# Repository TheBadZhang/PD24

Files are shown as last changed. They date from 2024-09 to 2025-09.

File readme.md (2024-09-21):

# PD24
> PD输入24V（可调输出）升压输出模块

## 原理图
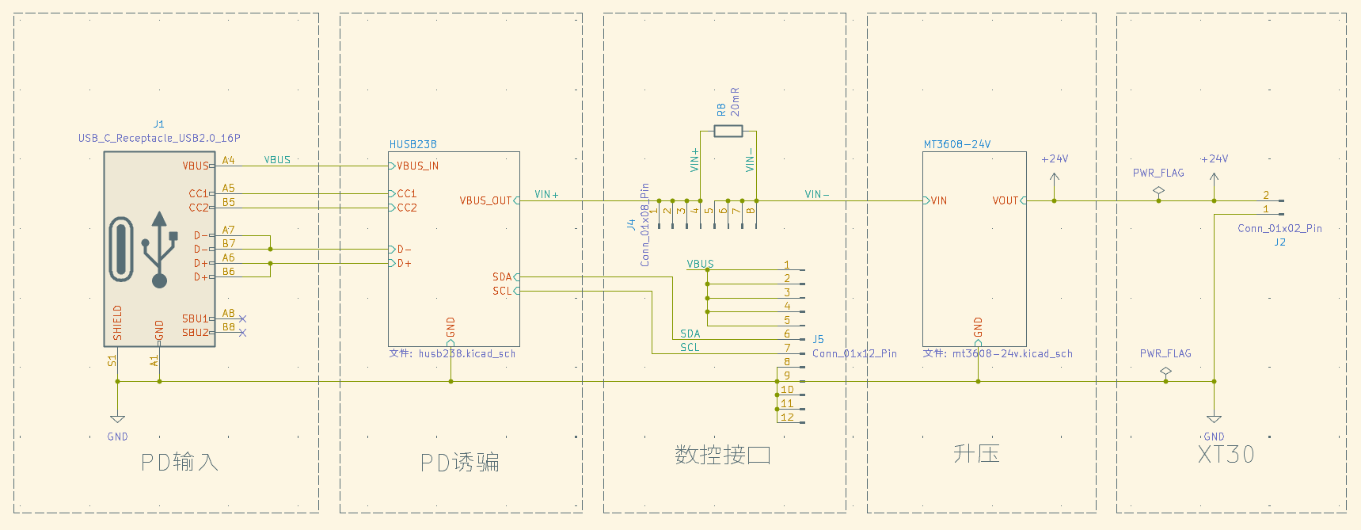
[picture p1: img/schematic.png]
原理图


简单来说就是使用`HUSB238`诱骗PD输出20V（诱骗不到20V就以此往下诱骗，最低5V）的电压，`CSD25402Q3A`过流控制，然后通过`MT3608`升压到24V输出

哪怕完全不支持PD，也可以输出24V，不过能够提供的功率就比较有限了

保留了数控接口，可以将`PD24`的输入电压和总线上的电流电压传给`PD24_ctrl`模块，计划通过INA226读取，并在OLED上显示

## 2D/3D Preview
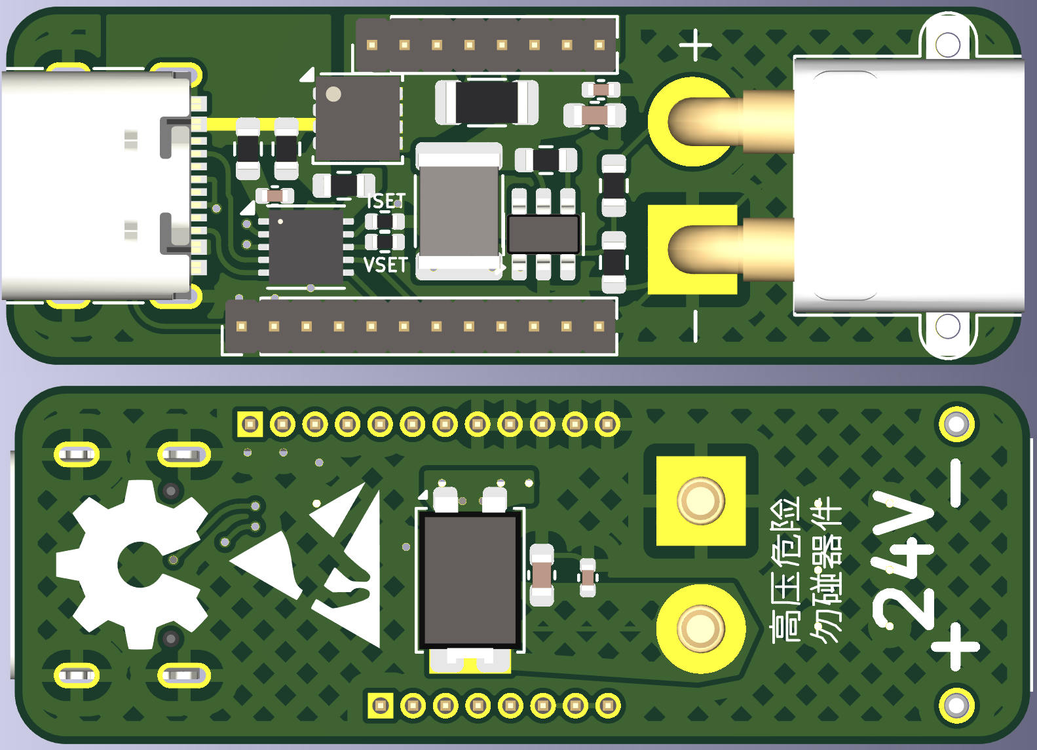
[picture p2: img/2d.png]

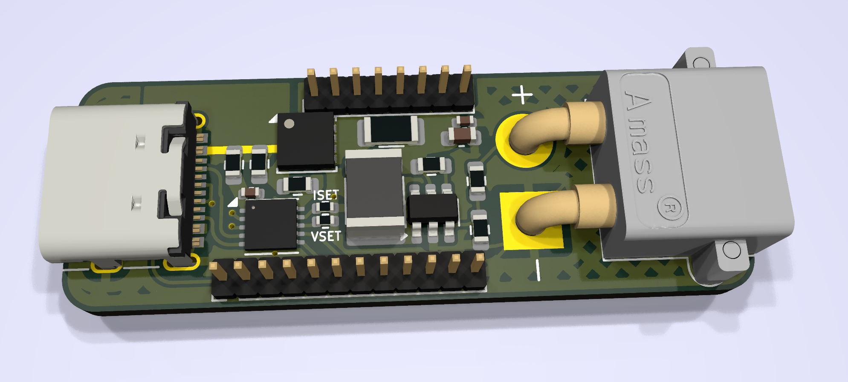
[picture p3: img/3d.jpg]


## 实物焊接
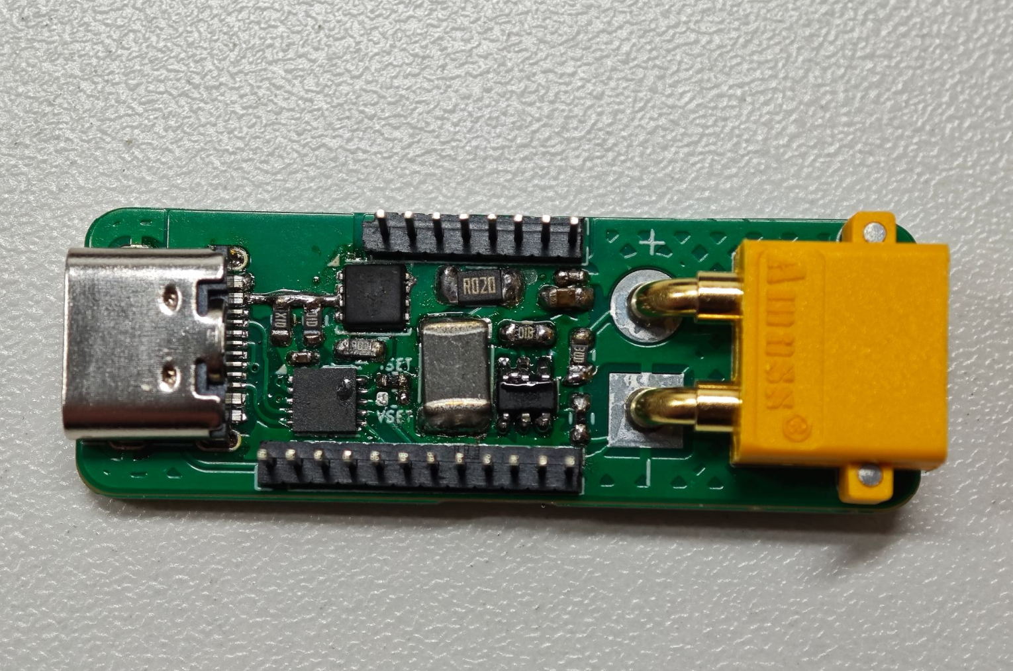
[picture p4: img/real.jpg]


> 因为没有开钢网，所以这些都是用烙铁上锡后用加热台焊接的，经常容易把控不住锡量，焊接比较难看，但是不影响功能

## 后话

这个模块一开始的时候因为电感没有到，所以我就直接焊上去用，结果`MT3608`和电感一下子就烧了，现在想想可能是因为没有焊接输出电容的原因，导致芯片震荡，最终烧掉

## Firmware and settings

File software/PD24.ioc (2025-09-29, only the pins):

Mcu.UserName=STM32G031G8Ux
PA13.Signal=SYS_SWDIO
PA14-BOOT0.Signal=SYS_SWCLK
PA2.GPIO_Label=INT1
PA2.Signal=GPXTI2
PA4.GPIO_Label=CS
PA4.Signal=GPIO_Output
PA5.Signal=SPI1_SCK
PA6.Signal=SPI1_MISO
PA7.Signal=SPI1_MOSI
PA8.GPIO_Label=INA226_ALERT
PA8.Signal=GPIO_Output
PB0.GPIO_Label=KEY1
PB0.Signal=GPIO_Input
PB1.GPIO_Label=KEY2
PB1.Signal=GPIO_Input
PB3.GPIO_Label=KEY3
PB3.Signal=GPIO_Input
PB7.Signal=I2C1_SDA
PB8.Signal=I2C1_SCL

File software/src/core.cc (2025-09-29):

#include "common.h"
#include "core.h"

#include "trick.h"
#include "main.h"

#include <stdio.h>
char strbuf[128] = {0};
uint8_t str_len = 0;

#include <stdint.h>
#include <stdio.h>
#include <string.h>

#include "font.h"
#include "ssd1312.h"

#include "ina226.h"

#include "ws2812.h"

#include "husb238.h"

#include "lis2dw12.h"


char uart_rx_buf[32];


//***********按键处理*************//
enum KEY_EVENT {
	KEY_NONE = 0,
	KEY_DOWN = 1,
	KEY_UP = 2
};

uint16_t key[4] = {0x00};
bool key_flag[4] = {true, true, true, true};

// 一般来说按键扫描函数需要按照5kHz的频率对按键进行扫描
void key_scan(void) {

	key[1] = (key[1] << 1) | ((!read(KEY1))?0x01:0x00);
	key[2] = (key[2] << 1) | ((!read(KEY2))?0x01:0x00);
	key[3] = (key[3] << 1) | ((!read(KEY3))?0x01:0x00);
}
/**
 * @brief 按键处理函数
 * @param i 按键编号
 * @return 0 无按键动作 1 按键按下 2 按键释放
 *
 * @note 该函数会自动处理按键的抖动
 * @note 改函数还需要和按键扫描函数配合使用
 */
uint8_t key_push(uint8_t i) {
	if (key[i] == 0xffff && key_flag[i]) {
		key_flag[i] = false;
		return 1;
	} else if (key[i] == 0x0000 && !key_flag[i]) {
		key_flag[i] = true;
		return 2;
	}

	return 0;
}
bool key_pressed(uint8_t i) {
	return key[i] == 0xffff;
}
bool key_released(uint8_t i) {
	return key[i] == 0x0000;
}


//***********INA226数据处理*************//
float bus_voltage;
int16_t current_raw;
float current;
uint16_t power_raw;
float power;
float power_sum = 0;


void ina226_sample(void) {
	bus_voltage = ina226_getBusV();
	current = ina226_getCurrent();
	power_raw = ina226_getPowerReg();
	power = ina226_getPower();

	// 将电压、电流、功率数据传给上位机
	// int bus_voltage_i = bus_voltage * 10000;
	// int current_i = current * 10000;
	// int power_i = power*10000;
	// str_len = sprintf(strbuf, "ina226: %d.%04d, %d.%04d, %d.%04d\r\n",
	// 	bus_voltage_i/10000, bus_voltage_i%10000,
	// 	current_i/10000, current_i%10000,
	// 	power_i/10000, power_i%10000);
	// HAL_UART_Transmit_DMA(&huart2, (const uint8_t*)strbuf, str_len);
}


template<class T>
T returnmin(T* list, uint8_t len) {
	T min = list[0];
	for (uint8_t i = 0; i < len; i++) {
		if (list[i] < min) {
			min = list[i];
		}
	}
	return min;
}
template<class T>
T returnmax(T* list, uint8_t len) {
	T max = list[0];
	for (uint8_t i = 0; i < len; i++) {
		if (list[i] > max) {
			max = list[i];
		}
	}
	return max;
}



//***********几个独立的数据信息处理*************//
class STATUS_BAR {
	uint16_t list[128] = {0};
	int32_t sum = 0;
	int32_t average = 0;
	int32_t d;
	uint8_t index = 0;
	bool if_index_max = false;

	// uint8_t x, y, w;
	uint8_t hw;   // 宽度的一半
public:

	void set_w(uint8_t w) {
		hw = w/2;
	}

	//* 数据条相关数值计算
	void calc(const uint16_t power_raw) {
		sum -= list[index];           // 减去旧值
		list[index] = power_raw;      // 更新新值
		sum += list[index];           // 加上新值

		// 计算平均值
		// 根据计数长短，平均值计算有所不同
		if (if_index_max) {
			average = sum / 128;
			d = (int32_t)power_raw*hw - sum*hw / 128;
		} else {
			average = sum / (index+1);
			if (index == 127) {
				if_index_max = true;
			}
			d = (power_raw - average) * hw;
		}

		index = (index + 1) % 128;

	}

	void draw(uint8_t y) {

		// ssd1312_showchar(64, 7, 0, num_6x8, 6, 8);

		if (d >= 0) {
			d /= (returnmax(list, 128) - average + 1);
			//* 样式1
			// ssd1312_drawSegs(64, 8, 64+d, 8, 0xff);

			//* 样式2
			for (uint8_t i = hw; i < hw+1+d; i++) {
				if (i%2==0) {
					if ((i-hw) % 10 == 0) {
						ssd1312_showchar(i-2, y+1, (i-hw)/10, num_6x8, 6, 8);
						ssd1312_drawSeg(i, y, 0x7f);
					} else {
						ssd1312_drawSeg(i, y, 0x78);
					}
				}
			}

		} else {
			d /= (average - returnmin(list, 128) + 1);

			//* 样式1
			// ssd1312_drawSegs(64+d, 8, 64, 8, 0xff);

			//* 样式2
			for (uint8_t i = hw; i > hw-1+d; i--) {
				if (i%2==0) {
					if ((hw-i) % 10 == 0) {
						ssd1312_showchar(i-2, y+1, (hw-i)/10, num_6x8, 6, 8);
						ssd1312_drawSeg(i, y, 0x7f);
					} else {
						ssd1312_drawSeg(i, y, 0x78);
					}
				}
			}
		}
	}

} power_bar;

class FLOW_CHART {
	float chart_data[128];
	int index_of_data = 0;
public:
	float max, min;
	void add_data(float data) {
		chart_data[index_of_data] = data;
		index_of_data = (index_of_data + 1) % 128;
	}

	void draw(void) {

		ssd1312_drawLine(0, 8, 0, 64, 1);
		ssd1312_drawLine(0, 63, 127, 63, 1);

		max = returnmax(chart_data, 128);
		min = returnmin(chart_data, 128);

		for (int i = 0, i_ = index_of_data; i < 127; i++, i_ = (i_+1) % 128) {
			if (((i+index_of_data)) % 8 == 1) {
				for (int j = 0; j < 7; j++) {
					ssd1312_drawPixel(i, 8*(j+1)+5, 1);
				}
			}

			if (i > 1)
			// 1. 点风格
			// ssd1312_drawPixel(i, 61-chart_data[i_]/max*58, 1);

			// 2. 线风格
			ssd1312_drawLine(i, 61-(chart_data[i_]-min)/(max-min)*40, i+1, 61-(chart_data[(i_+1)%128]-min)/(max-min)*40, 1);

			// 3. 矩形风格
			// ssd1312_drawLine(i, 61-chart_data[i_]/max*40, i, 61, 1);
		}
	}
} power_chart;

// 链接器选项 -u _printf_float
// 浮点数显示
void show_float(uint8_t x, uint8_t y, const float num) {
	// 位数控制，保证显示的数字个数为4个
	uint8_t fixed = 3;
	if (num >= 1000) {
		fixed = 0;
	} else if (num >= 100) {
		fixed = 1;
	} else if (num >= 10) {
		fixed = 2;
	}
	// -u _printf_float
	// str_len = sprintf(strbuf, "%.*f", fixed, num);         // 如果空间充足的话可以使用这个输出浮点数
	int out_num = num*1000;
	str_len = sprintf(strbuf, "%d.%0*d", out_num/1000, fixed, out_num%1000);
	// 因为画面中只能显示5位数字，所以这边设吹了人为上限为 5 位
	for (uint8_t i = 0; i < 5; i++) {
		if (isnum(strbuf[i])) {
			ssd1312_showchar(x, y, strbuf[i]-'0', num_10x24, 10, 24);
			x += 11;
		} else if (strbuf[i] == '.' && i != 4) {
			ssd1312_drawBox(x+1, y*8+18, 3, 3, 1);
			x += 6;
		}// 否则什么也不做
	}
}
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

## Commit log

2024-09-21 PD24验证完毕
    [PD24.kicad_pcb, PD24.kicad_sch, PD24_ctrl.kicad_pcb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]
2024-09-26 PD24 控制部分的PCB设计完成
    [PD24.kicad_pcb, PD24_ctrl.kicad_pcb, PD24_ctrl.kicad_sch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]
2024-09-30 软件部分更新
    在usbmeter的基础上增加了对lis2dw12的支持，可以直接进行重力识别切换显示方向，配置两双击识别可以清空累计的能量，优化了电流和功率的显示，不会再超出显示范围了。
    还增加了对husb238的控制和识别功能，可以通过按键直接切换诱骗的电压，但是在此设计上不太推荐切换，容易造成电流过大烧坏芯片
2024-10-01 优化按键输入控制，增加两个额外页面显示图表数据和PD数据，纠正HUSB238中的错误表述
2024-10-01 lis2dw12数据输出，添加了忘记添加的字体，优化了文本输出字体配置
2024-10-01 删除了无用的代码
2024-10-01 硬件1.0版本更新
    [PD24.kicad_pcb, PD24.kicad_sch, PD24_ctrl.kicad_pcb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]
2024-10-01 添加了项目文件
2024-10-19 改变了结构，下沉减少厚度
    为了实现这个目标，去掉了按键，将原先的buck电路替换成了ldo，但是会产生0.5W的热功耗，acc也放到了电源板上
    [PD24_ctrl.kicad_pcb, PD24_ctrl.kicad_sch, ssd1306.kicad_sch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]
2024-10-19 优化了布局的结构，使其能够在缩小的板框能够单面布局，适合焊接且不影响屏幕贴装
    [PD24_ctrl.kicad_pcb, PD24_ctrl.kicad_sch]
2024-10-19 硬件v1调整布局将肖特基二极管放置正面，便于贴片
    [PD24.kicad_pcb, PD24.kicad_sch, husb238.kicad_sch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]
2024-10-19 升压方案更换为sy7304，似乎能够通过更大的电流
    [sy7304-24v.kicad_sch]
2024-10-19 进一步优化了布局，减少了分叉，使大电流的回流路径更短
    [PD24.kicad_pcb]
2024-10-19 更换升压方案为同步整流，较大降低了升压电路的发热量，将acc和ldo放在电源板上
    [PD24.kicad_pcb, PD24.kicad_sch, husb238.kicad_sch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]
2024-10-19 硬件版本v2，待验证
    [PD24.kicad_pcb, PD24.kicad_sch, PD24_ctrl.kicad_pcb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]
2025-09-29 lis2dw12由于错误配置了cs脚，导致进入了spi模式，但电路设计上为iic的连接方式，无法读取方向，现在已经修正，但是代码设置成了固定方向。同步升压整流确实降低了不少发热，但是好像添加的ldo由于oled电流较大，带来的额外热量更多，之后可能还是考虑使用dcdc降压
    [PD24.kicad_pcb, PD24.kicad_sch, PD24_ctrl.kicad_pcb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]
